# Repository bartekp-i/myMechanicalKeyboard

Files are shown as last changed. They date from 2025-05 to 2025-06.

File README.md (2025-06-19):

# 75% Custom Mechanical Keyboard PCB Documentation  
**A compact, RP2040-powered keyboard with USB-C and OLED support.**  

---

## Overview  
This project is a custom 75% mechanical keyboard PCB designed around the Raspberry Pi RP2040 microcontroller. It features a non-standard QWERTY layout with 83 keys, USB-C connectivity with robust signal filtering, ESD protection, and support for a 0.96-inch RGB OLED module. The PCB is manufactured by JLCPCB and ready for soldering and programming.  

---

## Features  
- **RP2040 Microcontroller**: Dual-core ARM Cortex-M0+ for flexible firmware customization.  
- **USB-C Connectivity**: Built-in signal filtering and ESD protection (TVS diode) on D+/D- lines.  
- **Power Regulation**: 3.3V LDO Regulator (SPX5205M5-L-3-3/TR) for stable power delivery.  
- **QSPI Flash**: W25Q16JVUXIQ (2MB) for firmware storage.  
- **Precision Timing**: ABM8-272-T3 12MHz crystal oscillator.  
- **OLED Support**: Pads/THT headers for a 0.96-inch RGB OLED module.  
- **Debugging**: SWD (Serial Wire Debug) pins for firmware flashing/troubleshooting.  
- **Mechanical Design**:  
  - 75% layout (83 keys).  
  - Custom plate and back panel.  
  - Stabilizers for Space, Shift, Enter, and Backspace keys.  
  - AKKO V3 Pro Yellow switches (pre-lubed linear).  
  - Switching diodes for every key (anti-ghosting).  

---

## Hardware Details  

### RP2040 Microcontroller  
- Handles key matrix scanning, USB communication, and peripheral control.  
- Connected peripherals:  
  - **QSPI Flash**: Stores firmware and configuration data.  
  - **ABM8-272-T3 Oscillator**: Provides precise timing for USB communication.  
  - **Boot Button**: For entering firmware update mode.  
  - **SWD Pins**: 1x3 header for programming/debugging.  

### USB-C and Signal Integrity  
- **ESD Protection**: TVS diodes on D+/D- lines to protect against electrostatic discharge.  
- **Filtering**: Ferrite beads/RC filters to reduce noise on data lines.  

### Power Regulation  
- **SPX5205M5-L-3-3/TR LDO**: Converts USB 5V to 3.3V for RP2040 and peripherals.  
- Max current: 150mA (sufficient for RP2040, OLED, and peripherals).  

### Keyboard Matrix  
- **83-Key Layout**: Non-standard 75% design (see `Layout/` directory for matrix mapping).  
- **Switching Diodes**: Each key has a diode (1N4148 or similar) to prevent "ghosting" by blocking reverse current in the matrix.  

### Stabilizers  
- Required for longer keys: Spacebar, Enter, Backspace, and Shift (supports Cherry-style stabilizers).  

### OLED Module  
- **0.96-inch RGB OLED**: Connected via SPI.  
- Mounting: THT pads or header pins for secure attachment.
- Finally I decided to not use it due to current draw considerations. 

---

## Design & Manufacturing  
- **PCB**: Designed in KiCad (files in `Hardware/`).   
- **Manufacturing**:  
  - JLCPCB 2-layer PCB with white solder mask finish.  
  - SMD components can be pre-soldered.  

---

## Firmware  
- Coded using *QMK*-RP2040 is compatible with this software.  
- Example firmware available in `Firmware/`.  

---

## Build Instructions  
1. **Solder Components**:  
   - Diodes (orient cathode stripe correctly).  
   - RP2040, USB-C port, oscillator, and regulator.  
   - SWD header and OLED pins.  
2. **Mount Stabilizers**: Clip-in Cherry stabilizers for large keys.  
3. **Install Switches**: Secure AKKO V3 Pro switches into the plate and solder to PCB.  
4. **Attach OLED**: Solder headers or directly mount the OLED module.  
5. **Flash Firmware**: Use SWD or UF2 bootloader (press boot button while plugging in USB).  

---

## Acknowledgements  
- JLCPCB for PCB manufacturing.  
- Raspberry Pi Foundation for RP2040.  

## 📸 Photos!  

**Keyboard layout** 
keyboard-layout

**Schematic** 



**PCB Layout**


**Keyboard Plate**


**Back Plate**


**3D PCB Layout**


**3D Keyboard Plate**


**3D Back Plate**


**Boards After Manufacturing**
de2a45c0-26ce-4094-b5c6-7f7046fe6de4
ff16e77b-f6f2-4f7a-a8ca-ae126aca71c9
aa148c33-f10a-49f3-b886-1f6bd5d3fd8b
42f9e057-b715-42d8-a504-73b2bb60c914

**Fully Assembled Product**



---  
*Designed with Kicad by Bartosz Piotrowski.*

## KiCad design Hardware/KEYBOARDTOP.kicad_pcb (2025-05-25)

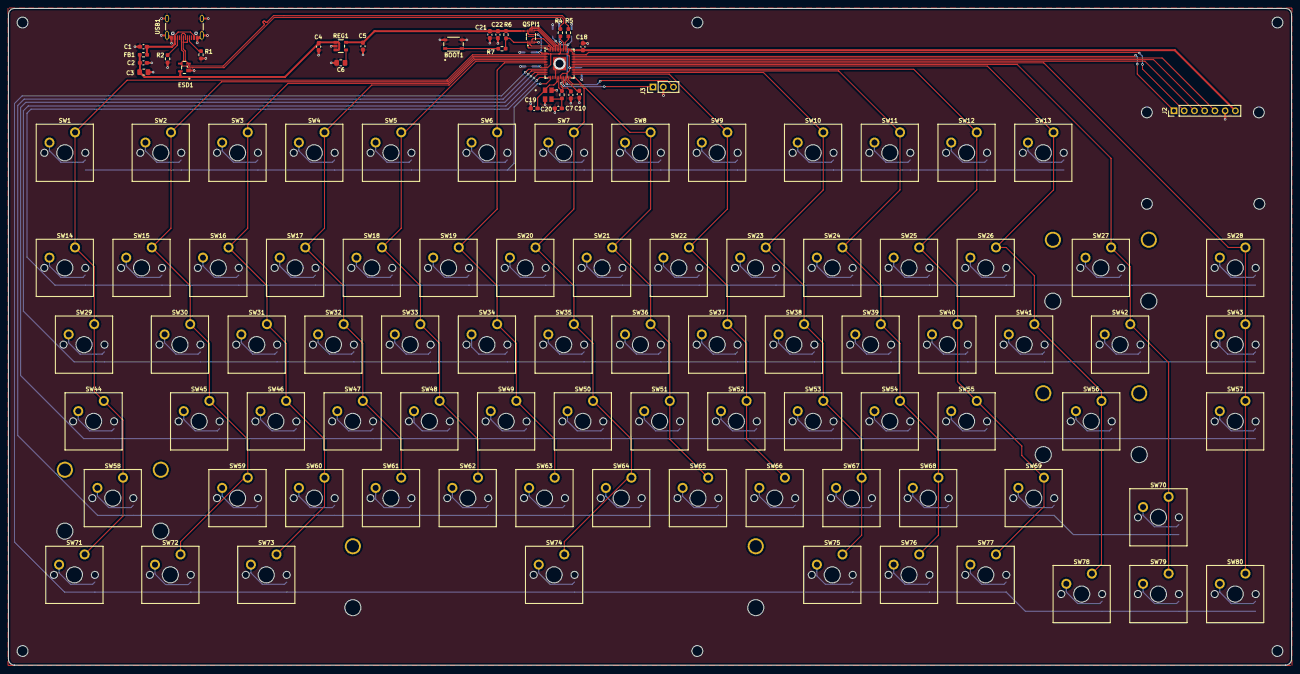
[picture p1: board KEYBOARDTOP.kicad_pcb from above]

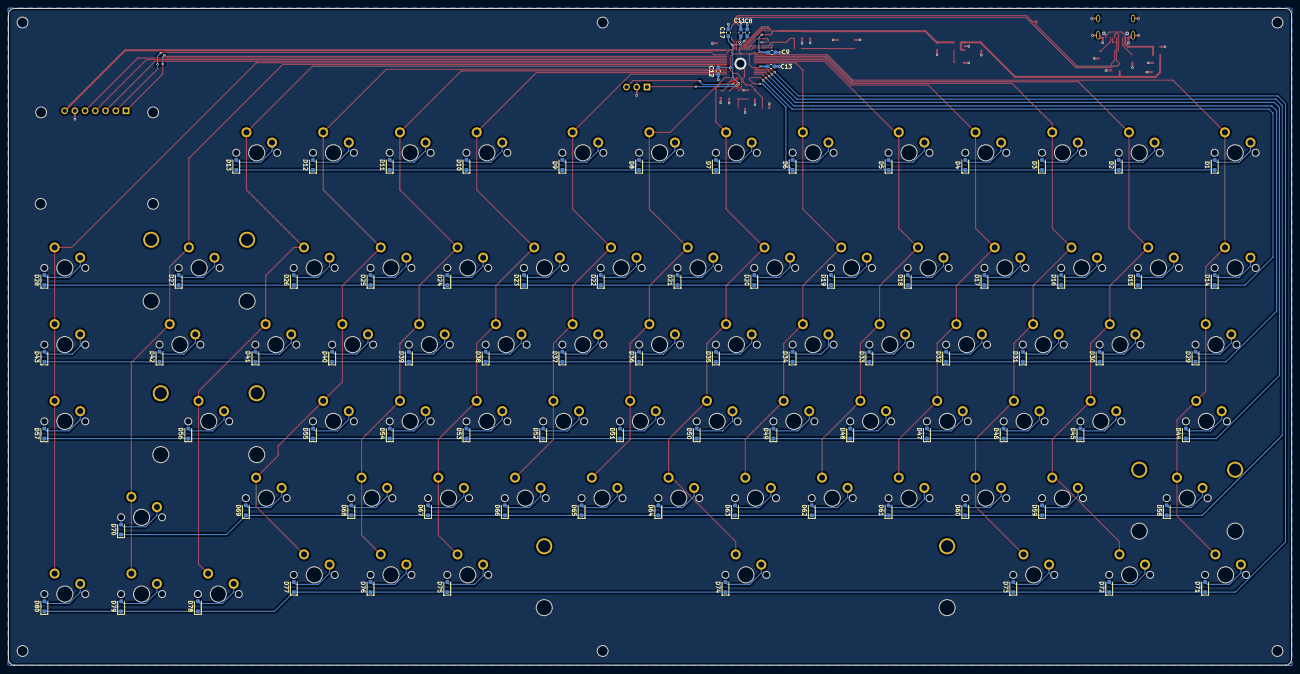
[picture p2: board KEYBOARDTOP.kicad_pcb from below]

Board: 2 copper layers, 318.5 x 163.0 mm, 200 parts (86 on the bottom side), 130 nets.

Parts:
BOOT1: SKRPABE010; SW4_SKRPABE010_ALPS
C1: 10nF; C_0603_1608Metric_Pad1.08x0.95mm_HandSolder
C2: 0.1uF; C_0603_1608Metric_Pad1.08x0.95mm_HandSolder
C3: 10uF; C_0805_2012Metric_Pad1.18x1.45mm_HandSolder
C4, C5: 1uF; C_0603_1608Metric_Pad1.08x0.95mm_HandSolder
C6: NO-FIT(10u); C_0805_2012Metric_Pad1.18x1.45mm_HandSolder
C7, C8, C9, C10, C11, C12, C13, C21: 100n; C_0603_1608Metric_Pad1.08x0.95mm_HandSolder
C17, C18: 1u; C_0603_1608Metric_Pad1.08x0.95mm_HandSolder
C19, C20: 15pF; C_0603_1608Metric_Pad1.08x0.95mm_HandSolder
C22: 2u2; C_0603_1608Metric_Pad1.08x0.95mm_HandSolder
D1, D2, D3, D4, D5, D6, D7, D8, D9, D10, D11, D12, D13, D14, D15, D16, D17, D18, D19, D20, D21, D22, D23, D24, D25, D26, D27, D28, D29, D30, D31, D32, D33, D34, D35, D36, D37, D38, D39, D40, D41, D42, D43, D44, D45, D46, D47, D48, D49, D50, D51, D52, D53, D54, D55, D56, D57, D58, D59, D60, D61, D62, D63, D64, D65, D66, D67, D68, D69, D70, D71, D72, D73, D74, D75, D76, D77, D78, D79, D80: D_Small; D_SOD-323_HandSoldering
ESD1: PRTR5V0U2X_215; SOT143B_PRTR5V0U2X_215_NEX
FB1: 120/100MHZ; R_0603_1608Metric_Pad0.98x0.95mm_HandSolder
J2: Conn_01x07; PinHeader_1x07_P2.54mm_Vertical
J3: Conn_01x03; PinHeader_1x03_P2.54mm_Vertical
QSPI1: W25Q16JVUXIQ; W25Q16JVUXIQ_WIN
R1, R2: 5.1k; R_0603_1608Metric_Pad0.98x0.95mm_HandSolder
R3: 1k; R_0603_1608Metric_Pad0.98x0.95mm_HandSolder
R4, R5: 27R; R_0603_1608Metric_Pad0.98x0.95mm_HandSolder
R6: No-Fit(1k); R_0603_1608Metric_Pad0.98x0.95mm_HandSolder
R7: 1K; R_0603_1608Metric_Pad0.98x0.95mm_HandSolder
REG1: SPX5205M5-L-3-3/TR; SP6201EM5
S1: MX_stab; STAB_MX_P_6.25u
S2: MX_stab; STAB_MX_P_2u
S3, S4: MX_stab; STAB_MX_P_2.25u
SW1: ESC; SW_Cherry_MX_PCB_1.00u
SW2: F1; SW_Cherry_MX_PCB_1.00u
SW3: F2; SW_Cherry_MX_PCB_1.00u
SW4: F3; SW_Cherry_MX_PCB_1.00u
SW5: F4; SW_Cherry_MX_PCB_1.00u
SW6: F5; SW_Cherry_MX_PCB_1.00u
SW7: F6; SW_Cherry_MX_PCB_1.00u
SW8: F7; SW_Cherry_MX_PCB_1.00u
SW9: F8; SW_Cherry_MX_PCB_1.00u
SW10: F9; SW_Cherry_MX_PCB_1.00u
SW11: F10; SW_Cherry_MX_PCB_1.00u
SW12: F11; SW_Cherry_MX_PCB_1.00u
SW13: F12; SW_Cherry_MX_PCB_1.00u
SW14: "~`"; SW_Cherry_MX_PCB_1.00u
SW15: 1; SW_Cherry_MX_PCB_1.00u
SW16: 2; SW_Cherry_MX_PCB_1.00u
SW17: 3; SW_Cherry_MX_PCB_1.00u
SW18: 4; SW_Cherry_MX_PCB_1.00u
SW19: 5; SW_Cherry_MX_PCB_1.00u
SW20: 6; SW_Cherry_MX_PCB_1.00u
SW21: 7; SW_Cherry_MX_PCB_1.00u
SW22: 8; SW_Cherry_MX_PCB_1.00u
SW23: 9; SW_Cherry_MX_PCB_1.00u
SW24: 0; SW_Cherry_MX_PCB_1.00u
SW25: -; SW_Cherry_MX_PCB_1.00u
SW26: +; SW_Cherry_MX_PCB_1.00u
SW27: backspace; SW_Cherry_MX_PCB_2.00u
SW28: pg_up; SW_Cherry_MX_PCB_1.00u
SW29: tab; SW_Cherry_MX_PCB_1.50u
SW30: q; SW_Cherry_MX_PCB_1.00u
SW31: w; SW_Cherry_MX_PCB_1.00u
SW32: e; SW_Cherry_MX_PCB_1.00u
SW33: r; SW_Cherry_MX_PCB_1.00u
SW34: t; SW_Cherry_MX_PCB_1.00u
SW35: y; SW_Cherry_MX_PCB_1.00u
SW36: u; SW_Cherry_MX_PCB_1.00u
SW37: i; SW_Cherry_MX_PCB_1.00u
SW38: o; SW_Cherry_MX_PCB_1.00u
SW39: p; SW_Cherry_MX_PCB_1.00u
SW40: [; SW_Cherry_MX_PCB_1.00u
SW41: ]; SW_Cherry_MX_PCB_1.00u
SW42: |; SW_Cherry_MX_PCB_1.50u
SW43: pg_down; SW_Cherry_MX_PCB_1.00u
SW44: caps; SW_Cherry_MX_PCB_1.75u
SW45: a; SW_Cherry_MX_PCB_1.00u
SW46: s; SW_Cherry_MX_PCB_1.00u
SW47: d; SW_Cherry_MX_PCB_1.00u
SW48: f; SW_Cherry_MX_PCB_1.00u
SW49: g; SW_Cherry_MX_PCB_1.00u
SW50: h; SW_Cherry_MX_PCB_1.00u
SW51: j; SW_Cherry_MX_PCB_1.00u
SW52: k; SW_Cherry_MX_PCB_1.00u
SW53: l; SW_Cherry_MX_PCB_1.00u
SW54: :; SW_Cherry_MX_PCB_1.00u
SW55: "; SW_Cherry_MX_PCB_1.00u
SW56: enter; SW_Cherry_MX_PCB_2.25u
SW57: delete; SW_Cherry_MX_PCB_1.00u
SW58: shift; SW_Cherry_MX_PCB_2.25u
SW59: z; SW_Cherry_MX_PCB_1.00u
SW60: x; SW_Cherry_MX_PCB_1.00u
SW61: c; SW_Cherry_MX_PCB_1.00u
SW62: v; SW_Cherry_MX_PCB_1.00u
SW63: b; SW_Cherry_MX_PCB_1.00u
SW64: n; SW_Cherry_MX_PCB_1.00u
SW65: m; SW_Cherry_MX_PCB_1.00u
SW66: <; SW_Cherry_MX_PCB_1.00u
SW67: >; SW_Cherry_MX_PCB_1.00u
SW68: ?; SW_Cherry_MX_PCB_1.00u
SW69: shift_2; SW_Cherry_MX_PCB_1.75u
SW70: arrow_up; SW_Cherry_MX_PCB_1.00u
SW71: ctrl; SW_Cherry_MX_PCB_1.25u
SW72: windows; SW_Cherry_MX_PCB_1.25u
SW73: alt; SW_Cherry_MX_PCB_1.25u
SW74: spacebar; SW_Cherry_MX_PCB_6.25u
SW75: alt; SW_Cherry_MX_PCB_1.00u
SW76: fn; SW_Cherry_MX_PCB_1.00u
SW77: ctrl; SW_Cherry_MX_PCB_1.00u
SW78: arrow_left; SW_Cherry_MX_PCB_1.00u
SW79: arrow_down; SW_Cherry_MX_PCB_1.00u
SW80: arrow_right; SW_Cherry_MX_PCB_1.00u
U3: RP2040; QFN-56-1EP_7x7mm_P0.4mm_EP3.2x3.2mm
USB1: USB_C_Receptacle_USB2.0_16P; USB_C_Receptacle_GCT_USB4105-xx-A_16P_TopMnt_Horizontal
X1: ABM8-272-T3; ABM8-272-T3_ABR

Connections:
+1.1V: C7.1, C8.1, C17.1, U3.23 (DVDD), U3.45 (VREG_VOUT), U3.50 (DVDD)
+3.3V: C5.1, C9.1, C10.1, C11.1, C12.1, C13.1, C18.1, C21.1, C22.1, J2.7, QSPI1.8 (VCC), R6.2, REG1.5 (OUT), U3.1 (IOVDD), U3.10 (IOVDD), U3.22 (IOVDD), U3.26 (RUN), U3.33 (IOVDD), U3.42 (IOVDD), U3.43 (ADC_AVDD), U3.44 (VREG_IN), U3.48 (USB_VDD), U3.49 (IOVDD)
+5V: C2.1, C3.1, C4.1, ESD1.4, FB1.2, REG1.1 (IN), REG1.3 (EN)
/D+: ESD1.3, R4.1, USB1.A6 (D+), USB1.B6 (D+)
/D-: ESD1.2, R5.1, USB1.A7 (D-), USB1.B7 (D-)
/QSPI_SCLK: QSPI1.6 (CLK), U3.52 (QSPI_SCLK)
/QSPI_SD0: QSPI1.5 (DI(IO0)), U3.53 (QSPI_SD0)
/QSPI_SD1: QSPI1.2 (DO(IO1)), U3.55 (QSPI_SD1)
/QSPI_SD2: QSPI1.3 (/WP(IO2)), U3.54 (QSPI_SD2)
/QSPI_SD3: QSPI1.7 (/HOLD_or_/RESET(IO3)), U3.51 (QSPI_SD3)
/QSPI_SS: QSPI1.1 (/CS), R6.1, R7.1, U3.56 (QSPI_SS)
/SWCLK: J3.1, U3.24 (SWCLK)
/SWDIO: J3.3, U3.25 (SWD)
/USB+: R4.2, U3.47 (USB+)
/USB-: R5.2, U3.46 (USB-)
CS: J2.3, U3.37 (GPIO25)
DIN: J2.5, U3.39 (GPIO27_ADC1)
DS: J2.2, U3.41 (GPIO29_ADC3)
GND: BOOT1.3, BOOT1.4, C1.2, C2.2, C3.2, C4.2, C5.2, C6.2, C7.2, C8.2, C9.2, C10.2, C11.2, C12.2, C13.2, C17.2, C18.2, C19.2, C20.2, C21.2, C22.2, ESD1.1, J2.6, J3.2, QSPI1.4 (GND), R1.1, R2.2, REG1.2 (GND), U3.19 (TESTEN), U3.57 (GND), USB1.A1 (GND), USB1.A12 (GND), USB1.B1 (GND), USB1.B12 (GND), USB1.S1 (SHIELD), X1.2, X1.4
unnamed: BOOT1.1, BOOT1.2, R7.2
unnamed: C20.1, R3.2, X1.3
unnamed: D1.2 (A), SW1.1
unnamed: D2.2 (A), SW2.1
unnamed: D3.2 (A), SW3.1
unnamed: D4.2 (A), SW4.1
unnamed: D5.2 (A), SW5.1
unnamed: D6.2 (A), SW6.1
unnamed: D7.2 (A), SW7.1
unnamed: D8.2 (A), SW8.1
unnamed: D9.2 (A), SW9.1
unnamed: D10.2 (A), SW10.1
unnamed: D11.2 (A), SW11.1
unnamed: D12.2 (A), SW12.1
unnamed: D13.2 (A), SW13.1
unnamed: D14.2 (A), SW14.1
unnamed: D15.2 (A), SW15.1
unnamed: D16.2 (A), SW16.1
unnamed: D17.2 (A), SW17.1
unnamed: D18.2 (A), SW18.1
unnamed: D19.2 (A), SW19.1
unnamed: D20.2 (A), SW20.1
unnamed: D21.2 (A), SW21.1
unnamed: D22.2 (A), SW22.1
unnamed: D23.2 (A), SW23.1
unnamed: D24.2 (A), SW24.1
unnamed: D25.2 (A), SW25.1
unnamed: D26.2 (A), SW26.1
unnamed: D27.2 (A), SW27.1
unnamed: D28.2 (A), SW28.1
unnamed: D29.2 (A), SW29.1
unnamed: D30.2 (A), SW30.1
unnamed: D31.2 (A), SW31.1
unnamed: D32.2 (A), SW32.1
unnamed: D33.2 (A), SW33.1
unnamed: D34.2 (A), SW34.1
unnamed: D35.2 (A), SW35.1
unnamed: D36.2 (A), SW36.1
unnamed: D37.2 (A), SW37.1
unnamed: D38.2 (A), SW38.1
unnamed: D39.2 (A), SW39.1
unnamed: D40.2 (A), SW40.1
unnamed: D41.2 (A), SW41.1
unnamed: D42.2 (A), SW42.1
unnamed: D43.2 (A), SW43.1
unnamed: D44.2 (A), SW44.1
unnamed: D45.2 (A), SW45.1
unnamed: D46.2 (A), SW46.1
unnamed: D47.2 (A), SW47.1
unnamed: D48.2 (A), SW48.1
unnamed: D49.2 (A), SW49.1
unnamed: D50.2 (A), SW50.1
unnamed: D51.2 (A), SW51.1
unnamed: D52.2 (A), SW52.1
unnamed: D53.2 (A), SW53.1
unnamed: D54.2 (A), SW54.1
unnamed: D55.2 (A), SW55.1
unnamed: D56.2 (A), SW56.1
unnamed: D57.2 (A), SW57.1
unnamed: D58.2 (A), SW58.1
unnamed: D59.2 (A), SW59.1
unnamed: D60.2 (A), SW60.1
unnamed: D61.2 (A), SW61.1
unnamed: D62.2 (A), SW62.1
unnamed: D63.2 (A), SW63.1
unnamed: D64.2 (A), SW64.1
unnamed: D65.2 (A), SW65.1
unnamed: D66.2 (A), SW66.1
unnamed: D67.2 (A), SW67.1
unnamed: D68.2 (A), SW68.1
unnamed: D69.2 (A), SW69.1
unnamed: D70.2 (A), SW70.1
unnamed: D71.2 (A), SW71.1
unnamed: D72.2 (A), SW72.1
unnamed: D73.2 (A), SW73.1
unnamed: D74.2 (A), SW74.1
unnamed: D75.2 (A), SW75.1
unnamed: D76.2 (A), SW76.1
unnamed: D77.2 (A), SW77.1
unnamed: D78.2 (A), SW78.1
unnamed: D79.2 (A), SW79.1
unnamed: D80.2 (A), SW80.1
unnamed: C6.1, REG1.4 (RST/ADJ)
unnamed: R1.2, USB1.A5 (CC1)
unnamed: R2.1, USB1.B5 (CC2)
RST: J2.1, U3.40 (GPIO28_ADC2)
SCK: J2.4, U3.38 (GPIO26_ADC0)
Vbus: C1.1, FB1.1, USB1.A4 (VBUS), USB1.A9 (VBUS), USB1.B4 (VBUS), USB1.B9 (VBUS)
XIN: C19.1, U3.20 (XIN), X1.1
XOUT: R3.1, U3.21 (XOUT)
col0: SW1.2, SW14.2, SW29.2, SW44.2, SW58.2, SW71.2, U3.2 (GPIO0)
col1: SW2.2, SW15.2, SW30.2, SW45.2, SW59.2, SW72.2, U3.3 (GPIO1)
col2: SW3.2, SW16.2, SW31.2, SW46.2, SW60.2, SW73.2, U3.4 (GPIO2)
col3: SW4.2, SW17.2, SW32.2, SW47.2, SW61.2, U3.5 (GPIO3)
col4: SW5.2, SW18.2, SW33.2, SW48.2, SW62.2, U3.6 (GPIO4)
col5: SW6.2, SW19.2, SW34.2, SW49.2, SW63.2, U3.7 (GPIO5)
col6: SW7.2, SW20.2, SW35.2, SW50.2, SW64.2, SW74.2, U3.27 (GPIO16)
col7: SW8.2, SW21.2, SW36.2, SW51.2, SW65.2, U3.28 (GPIO17)
col8: SW9.2, SW22.2, SW37.2, SW52.2, SW66.2, U3.29 (GPIO18)
col9: SW10.2, SW23.2, SW38.2, SW53.2, SW67.2, SW75.2, U3.30 (GPIO19)
col10: SW11.2, SW24.2, SW39.2, SW54.2, SW68.2, SW76.2, U3.31 (GPIO20)
col11: SW12.2, SW25.2, SW40.2, SW55.2, SW69.2, SW77.2, U3.32 (GPIO21)
col12: SW13.2, SW26.2, SW41.2, SW56.2, SW78.2, U3.34 (GPIO22)
col13: SW27.2, SW42.2, SW70.2, SW79.2, U3.35 (GPIO23)
col14: SW28.2, SW43.2, SW57.2, SW80.2, U3.36 (GPIO24)
row0: D1.1 (K), D2.1 (K), D3.1 (K), D4.1 (K), D5.1 (K), D6.1 (K), D7.1 (K), D8.1 (K), D9.1 (K), D10.1 (K), D11.1 (K), D12.1 (K), D13.1 (K), U3.16 (GPIO13)
row1: D14.1 (K), D15.1 (K), D16.1 (K), D17.1 (K), D18.1 (K), D19.1 (K), D20.1 (K), D21.1 (K), D22.1 (K), D23.1 (K), D24.1 (K), D25.1 (K), D26.1 (K), D27.1 (K), D28.1 (K), U3.15 (GPIO12)
row2: D29.1 (K), D30.1 (K), D31.1 (K), D32.1 (K), D33.1 (K), D34.1 (K), D35.1 (K), D36.1 (K), D37.1 (K), D38.1 (K), D39.1 (K), D40.1 (K), D41.1 (K), D42.1 (K), D43.1 (K), U3.14 (GPIO11)
row3: D44.1 (K), D45.1 (K), D46.1 (K), D47.1 (K), D48.1 (K), D49.1 (K), D50.1 (K), D51.1 (K), D52.1 (K), D53.1 (K), D54.1 (K), D55.1 (K), D56.1 (K), D57.1 (K), U3.13 (GPIO10)
row4: D58.1 (K), D59.1 (K), D60.1 (K), D61.1 (K), D62.1 (K), D63.1 (K), D64.1 (K), D65.1 (K), D66.1 (K), D67.1 (K), D68.1 (K), D69.1 (K), D70.1 (K), U3.12 (GPIO9)
row5: D71.1 (K), D72.1 (K), D73.1 (K), D74.1 (K), D75.1 (K), D76.1 (K), D77.1 (K), D78.1 (K), D79.1 (K), D80.1 (K), U3.11 (GPIO8)
